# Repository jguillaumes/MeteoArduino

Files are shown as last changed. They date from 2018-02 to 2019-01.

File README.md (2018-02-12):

# MeteoArduino - Small Arduino-Based meteorological station

This project consists on building a basic meteorological monitoring and registering station using an 
Arduino and a few sensors.

It measures the basic weather parameters:
- Temperature
- Atmospheric pressure
- Humidity
- Light level

The data is logged into a microSD card and sent to a nearby receiver using a bluetooth link. The "station" has no user interface, apart from a RESET and a TEST button.

## Materials

### Sensors used

- Temperature sensor, based on a DS18B20 chip.
- Humidity sensor, based on a DHT22 chip. This chip also measures temperature, but that measurement will not be used
- Atmospheric pressure sensor, based on a BMP180 chip
- Light sensor, based on a photoresistor read analogically

### Communications

The device will use an HC-06 based Serial-to-Bluetooth transceiver to send the data it gets to a nearby computer which will do the graphing and reporting.

### Storage

Initial plans called to use a local microSD to store the data in case it could not be transmitted. This is being re-evaluated. The first version will **not** store any data locally.

### Microcontroller

The device will use a nano-Arduino clone as microcontroller. The possibility of using a *raw* MCU will be considered.

## General design

Due to the author soldering (dis)abilities, the different sensors will be bought in ready-to-use format. There are plenty of sources available for that, and they are very cheap.

## General information

The initial design called for a BMP-280 based barometric sensor. Unfortunately that piece of hardware does not tolerate the 5V level of the Arduino board. A bi-directional level converted capable of supporting I2C must be used, and I had no one available. So I switched to the less precise (but good enough) BMP-180, in a breakout form which includes resistors to make it able to stand a 5V signal level. The specific piece is this: https://www.amazon.es/gp/product/B00M1PMSF2/ref=oh_aui_detailpage_o00_s00?ie=UTF8&psc=1

The second version of this project will use a stand-alone ATMega328P running at 8MHz in an all 3.3V circuit so the use of the BMP-280 will be reconsidered.

The BMP-180 branch of this project contains the software adapted for the BMP-180. The master branch uses the BMP-280.

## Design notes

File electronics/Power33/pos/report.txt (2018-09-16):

Info: Output directory '/Users/jguillaumes/git/MeteoArduino/electronics/Power33/pos' created.

Info: Front side (top side) place file: '/Users/jguillaumes/git/MeteoArduino/electronics/Power33/pos/Power33-top.pos'.
Info: Component count: 1.
Info: Back side (bottom side) place file: '/Users/jguillaumes/git/MeteoArduino/electronics/Power33/pos/Power33-bottom.pos'.
Info: Component count: 0.
Info: Full component count: 1

Component Placement File generation OK.
Info: Front side (top side) place file: '/Users/jguillaumes/git/MeteoArduino/electronics/Power33/pos/Power33-top.pos'.
Info: Component count: 1.
Info: Back side (bottom side) place file: '/Users/jguillaumes/git/MeteoArduino/electronics/Power33/pos/Power33-bottom.pos'.
Info: Component count: 0.
Info: Full component count: 1

Component Placement File generation OK.

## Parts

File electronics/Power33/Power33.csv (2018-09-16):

Id | Designator | Package | Quantity | Designation | Supplier and ref
1 | C1 | CP_Radial_D5.0mm_P2.50mm | 1 | 10uf
2 | C2 | CP_Radial_D5.0mm_P2.50mm | 1 | 10uF
3 | D1 | LED-3MM | 1 | LED
4 | J1 | USB_Micro-B_Molex-105017-0001 | 1 | USB_OTG
5 | J2,J3,J4 | Pin_Header_Straight_1x02_Pitch2.54mm | 3 | Conn_01x02_Male
6 | R1 | R_Axial_DIN0414_L11.9mm_D4.5mm_P5.08mm_Vertical | 1 | 470
7 | U1 | TO-220_Vertical | 1 | LM1117-3.3

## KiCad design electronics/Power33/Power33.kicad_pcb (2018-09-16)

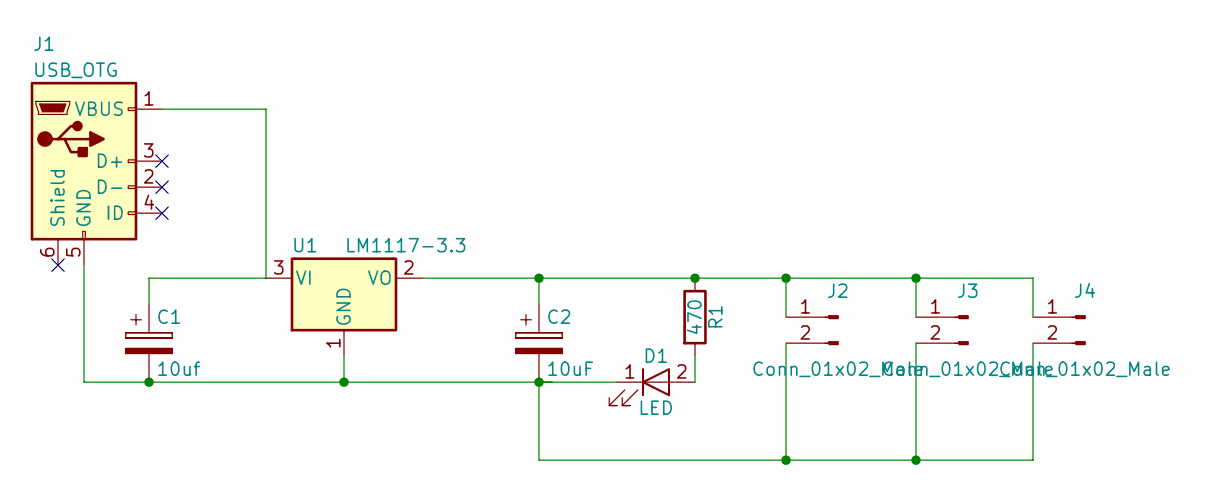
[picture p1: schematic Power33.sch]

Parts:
C1: 10uf; CP_Radial_D5.0mm_P2.50mm
C2: 10uF; CP_Radial_D5.0mm_P2.50mm
D1: LED; LED-3MM
J1: USB_OTG; USB_Micro-B_Molex-105017-0001
J2, J3, J4: Conn_01x02_Male; Pin_Header_Straight_1x02_Pitch2.54mm
R1: 470; R_Axial_DIN0414_L11.9mm_D4.5mm_P5.08mm_Vertical
U1: LM1117-3.3; TO-220_Horizontal

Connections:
unnamed: C1.1, J1.1 (VBUS), U1.3 (VI)
unnamed: C1.2, C2.2, D1.1 (K), J1.5 (GND), J2.2, J3.2, J4.2, U1.1 (GND)
unnamed: C2.1, J2.1, J3.1, J4.1, R1.1, U1.2 (VO)
unnamed: D1.2 (A), R1.2

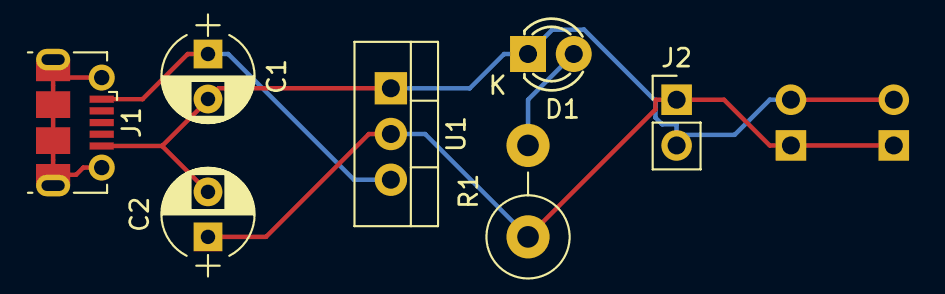
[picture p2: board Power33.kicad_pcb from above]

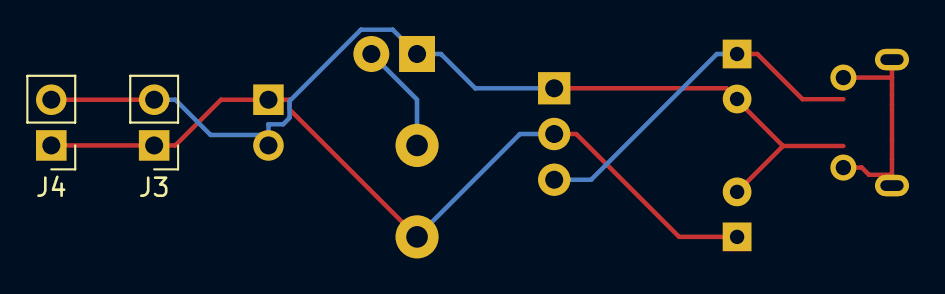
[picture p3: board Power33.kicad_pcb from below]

Board: 2 copper layers, 9 parts (2 on the bottom side), 4 nets.

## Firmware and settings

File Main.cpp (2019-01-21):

#include <Arduino.h>
#include <avr/sleep.h>
#include <avr/wdt.h>
#include <string.h>

// #define DEBUG 1

#include "clocks/MeteoClockRTC.h"
#include "clocks/MeteoClockSoft.h"

#include "sensors/ReadTemperature.h"
#include "sensors/ReadHumidity.h"
#include "sensors/ReadBarometer.h"
#include "sensors/ReadLight.h"

#include "HC05Module.h"
#include "MeteoEEPROM.h"
#include "MeteoMessages.h"

// Firmware version string
#define FWVERSION "03.01.00"
// External interrupt pin used by the RTC
#define SQ_PIN 3
// Size of the input buffer
#define INBUF_SIZE 40
// Size of the output buffer
#define OUTBUF_SIZE 128
// Timeout for command reads (in milis)
#define READ_TIMEOUT 1000
// MCU timer prescaler value
#define PRESCALER	 1024
// MCU timer tick frequency (in Hz)
#define INT_FREQ_HZ		1

MeteoClockRTC  rtcClock;
MeteoClockSoft softClock;
HC05Module bt(2);
MeteoEEPROM ee;
MeteoMessages msgs;

//struct {
//	struct EepromData data;
//} eeprom;

bool firstConnection = true;			// First connection flag
bool swClockSet = false;				// Is the software clock set?
bool rtcPresent = false;				// RTC detected flag
volatile bool doRead = true;			// Read sensors timing flag, read at startup
volatile bool wdTriggered = false;		// Flag: Watchdog triggered
enum deviceEnum { DE_CLOCK=0, DE_THERMOMETER=1, DE_HIGROMETER=2,
	              DE_BAROMETER=3, DE_LIGHT=4 };
char devList[] = "     ";				// List of present devices
static char line[OUTBUF_SIZE];			// Buffer to build output messages
static char line_with_check[OUTBUF_SIZE+8]; // Buffer for checksummed message
static char inBuff[INBUF_SIZE];			// Buffer for incoming commands

//+
// Fletcher 16 Checksum algorithm
// From https://www.luisllamas.es/arduino-checksum/
// (Thanks!)
//-
uint16_t ChecksumFletcher16(byte *data, size_t count )
{
   uint8_t sum1 = 0;
   uint8_t sum2 = 0;

   for(size_t index = 0; index < count; ++index )
   {
      sum1 = sum1 + (uint8_t)data[index];
      sum2 = sum2 + sum1;
   }
   return (sum2 << 8) | sum1;
}



//+
// Put the MCU to sleep
// Use IDLE mode to get the USART interrupts
// Remember the goal is not to save power, but to have correct
// timing of our readings
//-
void sleepNow() {
	set_sleep_mode(SLEEP_MODE_IDLE);
	sleep_mode();
}

//+
// RTC SQW interrupt service routine
// It keeps a counter of invocations. Each pollDelay seconds
// it will raise the global doRead flag so the main loop will
// make a sensor reading.
//-
void sqInterrupt() {
	static int sqCounter = -1;			// The flag is up at startup, so we have
										// to count from minus one.
	wdt_reset();						// Reset the watchdog timer
	if (++sqCounter >= ee.data.pollDelay) {
		doRead = true;
		sqCounter = 0;
	}
}

//+
// Watchdog interrupt routine.
// Resets itself and asserts the 'watchdog triggered' and
// 'time to read' flags.
//-
ISR(WDT_vect) {
	wdTriggered = true;
	doRead = true;
}
//+
// MCU timer1 compare interruption
//-
ISR(TIMER1_COMPA_vect) {
	static int timCounter = -1;

	wdt_reset();
		if (++timCounter >= ee.data.pollDelay) {
		doRead = true;
		timCounter = 0;
	}
}


//+
// Enable the MCU timer
//-
void enableMCUTimer() {
	uint32_t matchReg = F_CPU / (PRESCALER * INT_FREQ_HZ) - 1;
	cli();									// Inhibit interrupts
	TCCR1A = 0;
	TCCR1B = 0;
	TCNT1  = 0;
	OCR1A  = matchReg;
	TCCR1B |= (1 << WGM12);					// CTC mode
	TCCR1B |= (1 << CS12) | (1 << CS10);	// Set prescaler at 1024
	TIMSK1 |= (1 << OCIE1A);				// Enable timer comparer interrupt
	sei();									// Enable interrupts
}

//+
// Disable timer1
//-
void disableMCUTimer() {
	cli();
	TCCR1B  &= ~((1<<CS10) | (1<<CS12));
	sei();
}


//+
// Enable watchdog in interrupt + reset mode
//-
void enableWatchdog() {
    MCUSR &= ~(1<<WDRF);
    cli();							// Disable interrupts during timed change
    WDTCSR |= (1<<WDCE) | (1<<WDE);	// Enable changes, 4 cycles to go
    WDTCSR = (1<<WDP0) | (1<<WDP3);	// Clear reset mode, set 8s timeout
    sei();							// Enable interrupts
    WDTCSR |= (1<<WDIE) | (1<<WDE);	// Enable interrupt and reset modes
}

void checkClock() {
	bool clockNow = rtcPresent;

	if (!rtcClock.checkClock()) {
		rtcPresent = false;
		devList[DE_CLOCK] = '-';
		detachInterrupt(INT1);
		enableMCUTimer();
	} else {
		rtcPresent = true;
		devList[DE_CLOCK] = 'C';
		disableMCUTimer();
		rtcClock.enableInterrupt();
		if (!swClockSet) {
			DateTime now = rtcClock.getDateTime();
			softClock.setClock(now.year(), now.month(), now.day(),
					           now.hour(), now.minute(), now.second());
			swClockSet = true;
		}
		attachInterrupt(INT1, sqInterrupt, FALLING);
	}
	if (clockNow != rtcPresent) {
		if (rtcPresent) {
			msgs.getMessage(CLOCKDET, line);
		} else {
			msgs.getMessage(CLOCKLST, line);
		}
		Serial.println(line);
	}
}

void setup() {
	int rc=0;
	char msg[80];

	// Disable watchdog, just in case
	MCUSR=0;
	wdt_disable();

	Serial.begin(9600);

	while (!bt.begin()) {
		Serial.println("ERROR: No BT connection");
	}

	Serial.println("");

	ee.readEEPROM();
	// eeprom.data.pollDelay = 5;


#ifdef DEBUG
	sprintf(msg, "DEBUG: CPU clock: %ld", F_CPU);
	Serial.println(msg);
#endif

	rc = thPrepare();
	if (rc != 0) {
		msgs.getMessage(THERMNOK, line);
		Serial.println(line);
		devList[DE_THERMOMETER] = '-';
	} else {
		devList[DE_THERMOMETER] = 'T';
	}
	rc = higInitialize();
	if (rc != 0) {
		msgs.getMessage(HYGRONOK, line);
		Serial.println(line);
		devList[DE_HIGROMETER] = '-';
	} else {
		devList[DE_HIGROMETER] = 'H';
	}

	rc = barInitialize();
	if (rc != 0) {
		msgs.getMessage(BAROMNOK, line);
		Serial.println(line);
		devList[DE_BAROMETER] = '-';
	} else {
		devList[DE_BAROMETER] = 'P';
	}

	rc = lightInitialize();
	devList[DE_LIGHT] = 'L';

	checkClock();

	//+
	// Set up the interrupt pin
	// That pin will get the SQW signals from the RTC and will act
	// on the falling flank
	//-
	pinMode(SQ_PIN, INPUT_PULLUP);
	enableWatchdog();

	sprintf(msg, "INFO : F:%s W:%s N:%s DLY:%d", FWVERSION, ee.data.hwVersion,
			                                       ee.data.devName, ee.data.pollDelay);
	Serial.println(msg);


}

//+
// Read an incoming command from the serial line (hopefully connected to the HC-05)
// The accepted command terminators are NL or CR+NL
// If a command terminator has not been received in READ_TIMEOUT milliseconds
// the read will be rejected and a timeout will be signaled (returning FALSE).
//-
bool readCommand() {
	bool eos = false;
	bool timeout = false;
	int numChars = 0;
	char *buffPtr = inBuff;
	unsigned long timecontrol = millis();

	while (!eos && numChars < INBUF_SIZE && !timeout) {
		if (millis() - timecontrol < READ_TIMEOUT) {
			if (Serial.available()) {
				char c = Serial.read();
				if (c == 0x0a) {		// Got command terminator
					eos = true;
					*(buffPtr++) = 0x0;	// Terminate the command line
				} else if (c == 0x0d) {
					continue;			// Ignore CR by itself. The terminator must be NL or CR+NL
				} else {
					*(buffPtr++) = c;	// Got char, append to buffer
					numChars++;
				}
			}
		} else {
			timeout = true;			// Didn't get a complete command
			*(buffPtr++) = 0x0;		// Terminate partial command
		}
	}
	return !timeout;
}

//+
// Process a command string
//-
void processCommand(String cmd) {
	bool cmdOk = false;

	String theCmd = cmd.substring(0,5);
	if (theCmd.equals("TIME ")) {
		String t = cmd.substring(5,19);
		checkClock();
		if (rtcPresent) {
			rtcClock.setClock(t);
		}
		softClock.setClock(t);
		swClockSet = true;
		cmdOk = true;
	} else if (theCmd.equals("BYE  ")) {
		Serial.println("OK-BYE");
		cmdOk = true;
		for (int i=0; i<5 && bt.checkConnection(); i++) delay(1000);
		if (bt.checkConnection()) {
			Serial.println("KO-ONL");
		} else {
			firstConnection = true;
		}
		return;
	} else if (theCmd.equals("INFO ")) {
		sprintf(line, "INFO : F:%s W:%s N:%s DLY:%d", FWVERSION, ee.data.hwVersion,
				                                        ee.data.devName, ee.data.pollDelay);
		Serial.println(line);
		cmdOk = true;
	} else if (theCmd.equals("DLAY ")) {
		int newDelay = atoi(cmd.substring(5,7).c_str());
		if (newDelay < 1 || newDelay > 60) {
			Serial.println("KO-INV");
		} else {
			ee.data.pollDelay = newDelay;
			ee.writeEEPROM();
		}
		cmdOk = true;
	} else if (theCmd.equals("NAME ")) {
		strncpy(ee.data.devName, cmd.substring(5,13).c_str(), _SIZ_DEVNAME+1);
		ee.writeEEPROM();
		cmdOk = true;
	} else if (theCmd.equals("VERS ")) {
		strncpy(ee.data.hwVersion, cmd.substring(5,13).c_str(), _SIZ_HWVERSION+1);
		Serial.println("WARNING: Hardware version changed by command.");
		ee.writeEEPROM();
		cmdOk = true;
	}
	if (cmdOk) {
		Serial.println("OK-000");
	} else {
		sprintf(line, "KO-UNK [%s]", theCmd.c_str());
		Serial.println(line);
	}
}

//  TIME 20180220221700
//  BYE

//+
// Read the sensors and send a DATA line thru the USART
//-
void readSensors() {
	String theTime;
	float temp, press, humdt, light;
	uint16_t check = 0;

	// If we have an RTC, check it's still working. If not, switch to MPU soft clock
	if (rtcPresent) {
		checkClock();
		if (rtcPresent) {
			theTime = rtcClock.getClock();
		}
	}

	// If we've got no RTC, use software clock and check if it has came back
	if (!rtcPresent) {
		theTime = softClock.getClock();
		checkClock();
	}
	char stemp[10], shumt[10], spres[10], slght[10];

	temp = thRead();
	press = barRead();
	humdt = higRead();
	light = lightRead();

	if (temp==-999.00) {		// No thermometre?
		temp = barTemp();		// Try BMP180
		if (temp==-999.00) {	// No BMP180?
			temp = higTemp();	// Try DHT22
		}
		if (devList[DE_THERMOMETER] == 'T') {
			msgs.getMessage(THERMLST, line);
			Serial.println(line);
			devList[DE_THERMOMETER] = '-';
		}
	} else {
		if (devList[DE_THERMOMETER] == '-') {
			msgs.getMessage(THERMDET, line);
			Serial.println(line);
			devList[DE_THERMOMETER] = 'T';
		}
	}

	if (press == -999.00) {
		if (devList[DE_BAROMETER] == 'P') {
			msgs.getMessage(BAROMLST, line);
			Serial.println(line);
			devList[DE_BAROMETER] = '-';
		}
	} else {
		if (devList[DE_BAROMETER] == '-') {
			msgs.getMessage(BAROMDET, line);
			Serial.println(line);
			devList[DE_BAROMETER] = 'P';
		}
	}

	if (humdt == -999.00) {
		if (devList[DE_HIGROMETER] == 'H') {
			msgs.getMessage(HYGROLST, line);
			Serial.println(line);
			devList[DE_HIGROMETER] = '-';
		}
	} else {
		if (devList[DE_HIGROMETER] == '-') {
			msgs.getMessage(HYGRODET, line);
			Serial.println(line);
			devList[DE_HIGROMETER] = 'H';
		}
	}

	dtostrf(temp, 5, 2, stemp);
	dtostrf(press, 6, 2, spres);
	dtostrf(humdt, 5, 2, shumt);
	dtostrf(light, 6, 2, slght);

	sprintf(line, "DATA :C%s:F%s:T%s:H%s:P%s:L%s:D%s:W%s:N%s", theTime.c_str(), FWVERSION, stemp,
			shumt, spres, slght, devList,ee.data.hwVersion,ee.data.devName);
	check = ChecksumFletcher16((unsigned char *) line, strlen(line));
	sprintf(line_with_check,"%s:X%05u",line,check);

	if (bt.checkConnection()) {
		if (firstConnection) {
			msgs.getMessage(BEGINPGM, line);
			firstConnection = false;
		}
		Serial.println(line_with_check);
	}
}

//+
// Main loop
//-
void loop() {
	if (wdTriggered) {
		msgs.getMessage(WATCHDOG, line);
		Serial.println(line);
		Serial.flush();
		wdTriggered = false;
	}

	if (doRead) {
		doRead = false;
		readSensors();
		if (!swClockSet) {
			msgs.getMessage(TIMEREQS, line);
			Serial.println(line);
		}
		Serial.flush();
	}
	if (Serial.available()) {
		if (readCommand()) {
			Serial.flush();
		} else {
			msgs.getMessage(COMNDTMO, line);
			Serial.println(line);
		}
		processCommand(String(inBuff));
	}
	sleepNow();					// Wait for next interrupt
}

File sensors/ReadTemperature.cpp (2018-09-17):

#include "ReadTemperature.h"

OneWire thermometer(THERMOMETER_PIN);			// Thermometer OneWire handler
byte th_addr[8];								// Thermometer OneWire address

int thPrepare() {
	int result = -1;

#ifdef DEBUG
	Serial.println("DEBUG: Trying to initialize DS18B20 thermometer.");
#endif

	thermometer.reset_search();
	if (thermometer.search(th_addr)) {
		if (OneWire::crc8(th_addr, 7) != th_addr[7]) {
			Serial.println("ERROR: Thermometer CRC is not valid!");
			result = 2;
		} else {
			if (th_addr[0] != DS18B20) {
				Serial.println("ERROR: Unexpected chip signature");
				result = 4;
			} else {
				result = 0;
			}
		}
	} else {
		result = 8;
#ifdef DEBUG
		Serial.println("DEBUG: DS18B20 not found.");
#endif
	}
#ifdef DEBUG
	char buffer[80];
	sprintf(buffer, "DEBUG: End of DS18B20 prep, result=%d",result);
	Serial.println(buffer);
#endif
	return result;
}

float thRead() {
	byte data[12];								// Read buffer
	int i;
	byte crc;									// Data CRC
	byte cfg;									// Chip configuration byte
	int16_t raw;								// Raw/binary temperature

	float temp = 0;

	if (thPrepare() != 0) {
		return -999.0;
	}

	thermometer.reset();
	thermometer.select(th_addr);
	thermometer.write(TH_START_CONVERSION, 0);// Conversion, no parasitic power
	delay(750);									// Wait for conversion

	thermometer.reset();
	thermometer.select(th_addr);
	thermometer.write(TH_READ_SCRATCHPAD);		// Read temperature

	for (i = 0; i < 9; i++) {						// Get 9 bytes
		data[i] = thermometer.read();
	}
	crc = OneWire::crc8(data, 8);
	if (crc != data[8]) {
		Serial.println("ERROR: Thermometer data CRC is wrong");
		temp = -999.00;
		return temp;
	}

	cfg = data[4] & 0x60;						// Config byte
	raw = (data[1] << 8) | data[0];				// Raw temperature data (binary)

	// at lower res, the low bits are undefined, so let's zero them
	if (cfg == 0x00)
		raw = raw & ~7;  // 9 bit resolution, 93.75 ms
	else if (cfg == 0x20)
		raw = raw & ~3; // 10 bit res, 187.5 ms
	else if (cfg == 0x40)
		raw = raw & ~1; // 11 bit res, 375 ms
	// default is 12 bit resolution, 750 ms conversion time
	temp = (float) raw / 16.0;					// Get temp in Celsius

	return temp;
}

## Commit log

2018-02-01 - Removed Release/ from repository - Added light sensor - Changed thermometer PIN to free PIN10 for SPI - Added references to BT comms library and SD logger
2018-02-04 - Added tsa field to weather doc (unique, non opaque identifier) - Added logic to switch to a new index every day - Refactored part of the logic to weatherLib.py
2018-02-08 - python: use computed index name all the times instead of default one - Arduino code: conditionally print on Serial() - Add support for standalone microcontroller
    [StandAlone328.fzz]
2018-02-08 - Improved exception control to keep the process alive in case of ES failure - Refactored functions defined in weatherClient into weatherLib
2018-02-12 - Replace BMP280 by BMP180 pressure sensor (on new branch)
    [Main.cpp]
2018-02-12 - README.MD: Clarify the barometric sensor use
2018-02-18 - Old library cleanup - In progress implementation of data recorded based on 23LCV1024 - Add python program to fix bad ES data
    [Main.cpp]
2018-02-19 - Replace Adafruit DHTxx library for DHTLib. The Adafruit one does not work well with an MCU clocking at 8MHz - Added functions to read the DHT22 and BMP180 thermometers - Use od BMP180 and DHT22 the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
    [Main.cpp]
2018-02-20 - Added support for RTC-less operation. - Changed BT module to HC-05 connected via the UART instead of SoftwareSerial. - Added recovery of sensor failures. The MCU will try to reestablish connection 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
    [Main.cpp, ReadTemperature.cpp]
2018-05-07 - Bulk insert of measurements - work in progress:
2018-08-28 - Added software clock setting from RTC if available - Fixed fallback for RTC failure - Switched ADC reference to AREF pin
    [Main.cpp, ReadTemperature.cpp]
2018-08-29 - Add script to set the gizmo RTC to the current unix time - Stupid tsa fix (again) - Ignore garbage characters instead of abortting on reception
2018-09-11 - Switch to python logging module - Change index name field in Weather doc (because of name collision) - Correct mishandling of CTRL-C
2018-09-12 - Removed hardcoded addresses and UUIDs and moved them to config file - Removed remaining 'print' statements; now all logging is done using logMessage - Added config file template.
2018-09-14 - Added TSA assignation from the queue module (and corresponding control table) - Added separate thread to store observations in postgres
2018-09-15 - Changed template name to include the version - Added (again) Elasticsearch support, in a separate thread - Renamed _EL_ stuff to _ES_ (for elasticsearch) - Changed transactionality of sqlite3 acces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
2018-09-16 - Added Janitor and Watchdog threads - INI file reorganization - Added support to be run from any directory - Data files relocated to a ini-specified directory
2018-09-16 - Added database load tool (work in progress) - Minimal tweaks in logging
    [Power33-all.csv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]
2018-09-16 - Stop threads in case of unexpected exception on main trhread
2018-09-17 - Insert -999.0 values as nulls.
2018-09-19 - Added tool to recover and insert the dupe TSA documents - Added document id generation to the WeatherDB class - Corrected error en tool to recover non-TSAed documents
2018-09-19 - Fixed naming problems - Fixed insertion into db
2018-09-24 - Refactored watchdog class - BT-reading loop placed in its own thread, which is watched - The time-controlled threads (the janitor and the watchdog) use a Timer object to do their stuff, and check f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
2018-09-25 - Firmware: refactored clock handling into a polymorphic hyerarchy for hardware RTC and software timekeeping - Firmware: this fixes the RTC adjust time bug
    [Main.cpp]
2018-10-04 - Firmware 03.00.00: Timer/interrupt driven, with watchdog enabled for automatic recovery attempt.
2018-10-05 - Source tree cleanup: sensors and clock source files moved to specific subdirectories
2018-10-06 - Ooops! The NAME command did not write the EEPROM. Fixed. - Added VERS command to change the hardware version in EEPROM.
    [Main.cpp]
